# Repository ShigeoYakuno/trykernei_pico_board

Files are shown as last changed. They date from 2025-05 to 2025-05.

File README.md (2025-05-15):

# ベースボード

## 方針
- カバーなどが安く買え、種類も豊富なためラズパイ4Bサイズで作る。
- 40pinのコネクタ、M2.5サイズのホールもそのまま採用
- プログラム変更をSDカード経由で行いたいため、カードスロットを標準搭載する
- 3.7Vリポバッテリーでも起動できるよう構成する

### 全体



### 表面


### 裏面



## 3D正面


## 3D裏面



## BOM


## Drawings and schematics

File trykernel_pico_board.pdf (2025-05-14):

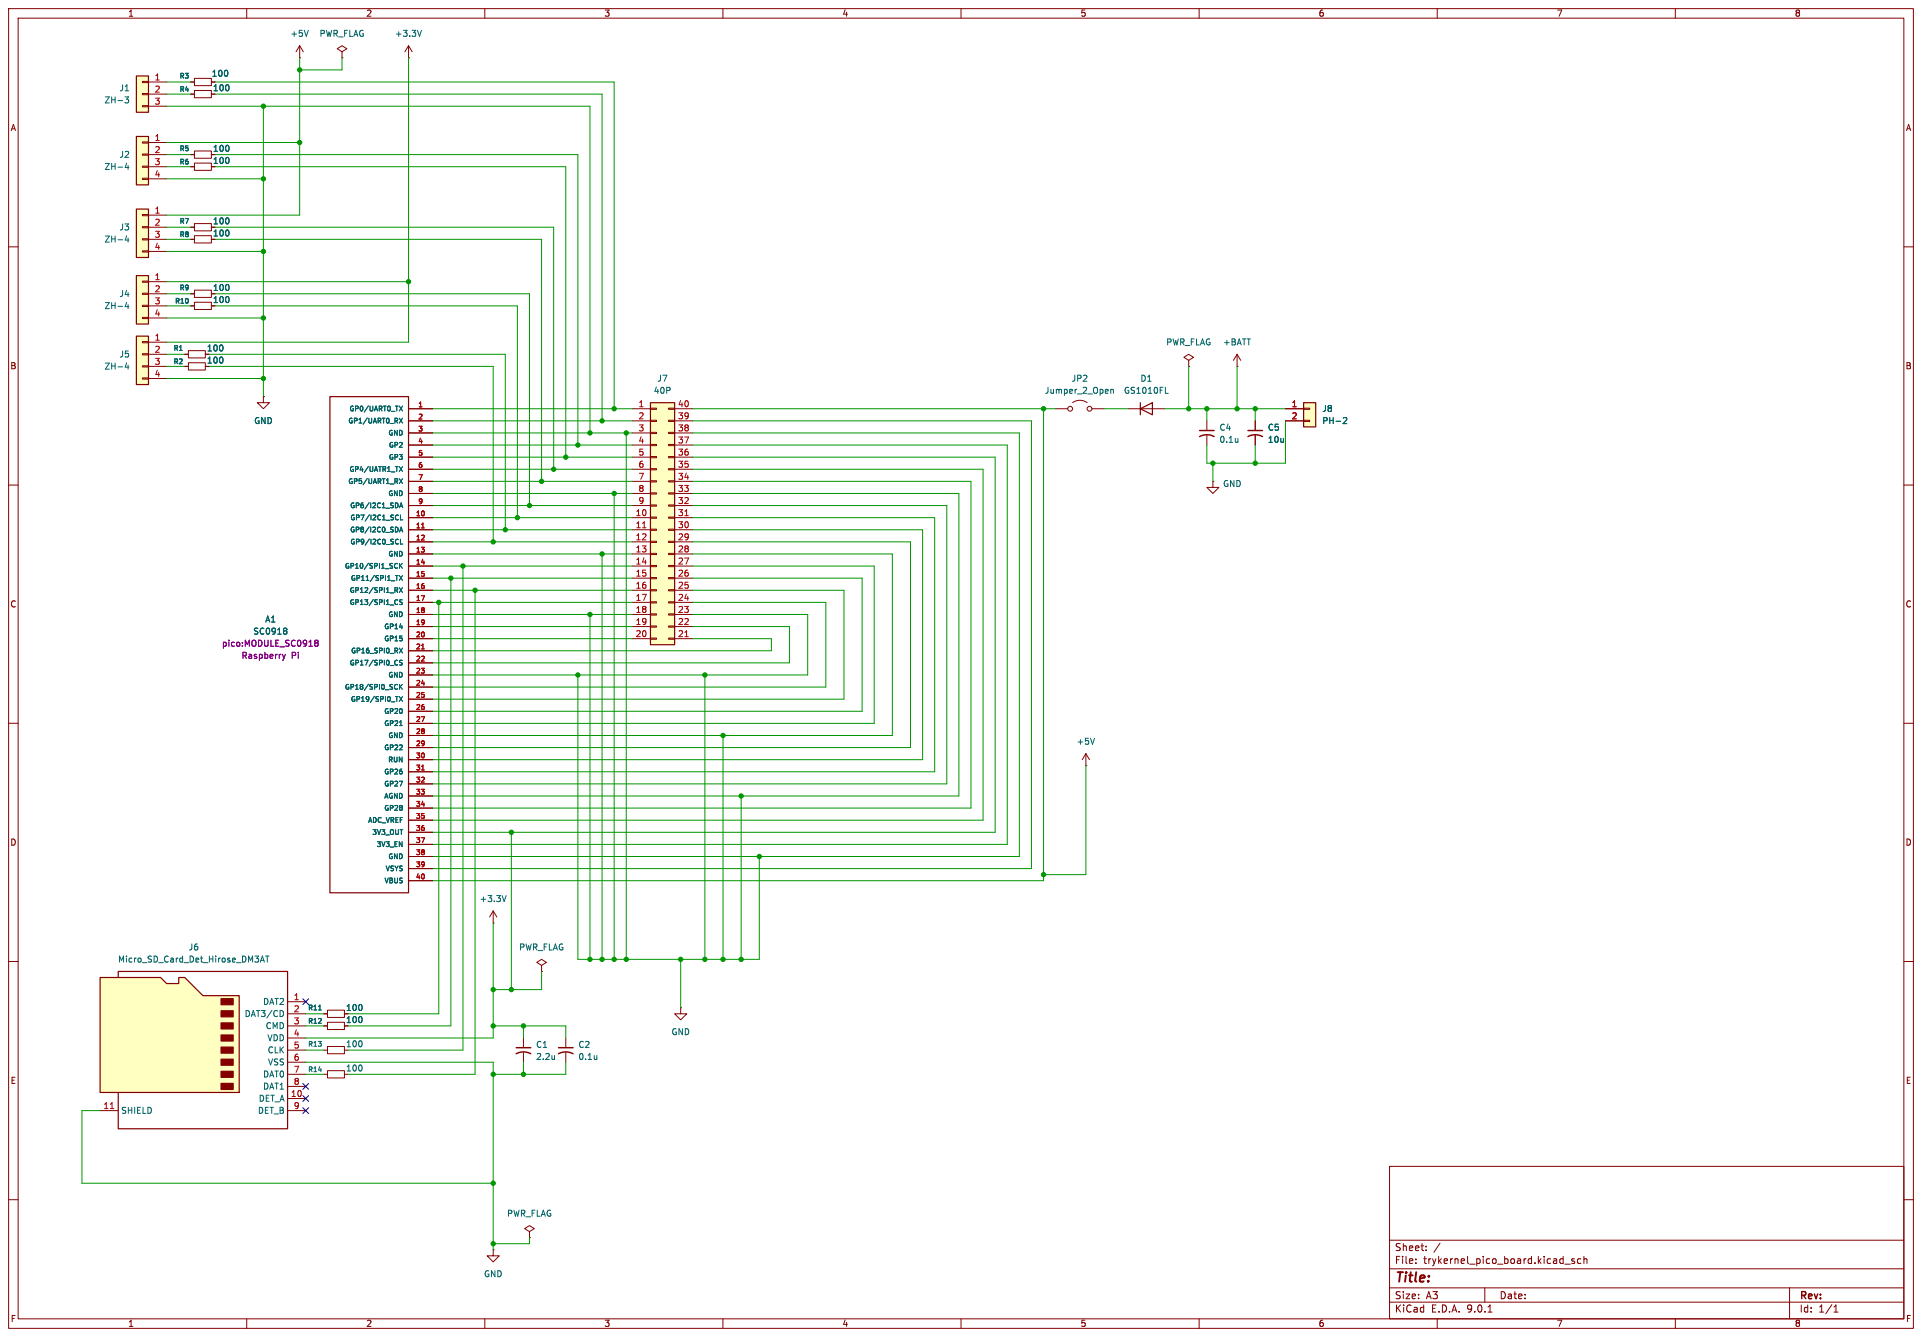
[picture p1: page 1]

Id: 1/1 Title: File: trykernel_pico_board.kicad_sch Sheet: /

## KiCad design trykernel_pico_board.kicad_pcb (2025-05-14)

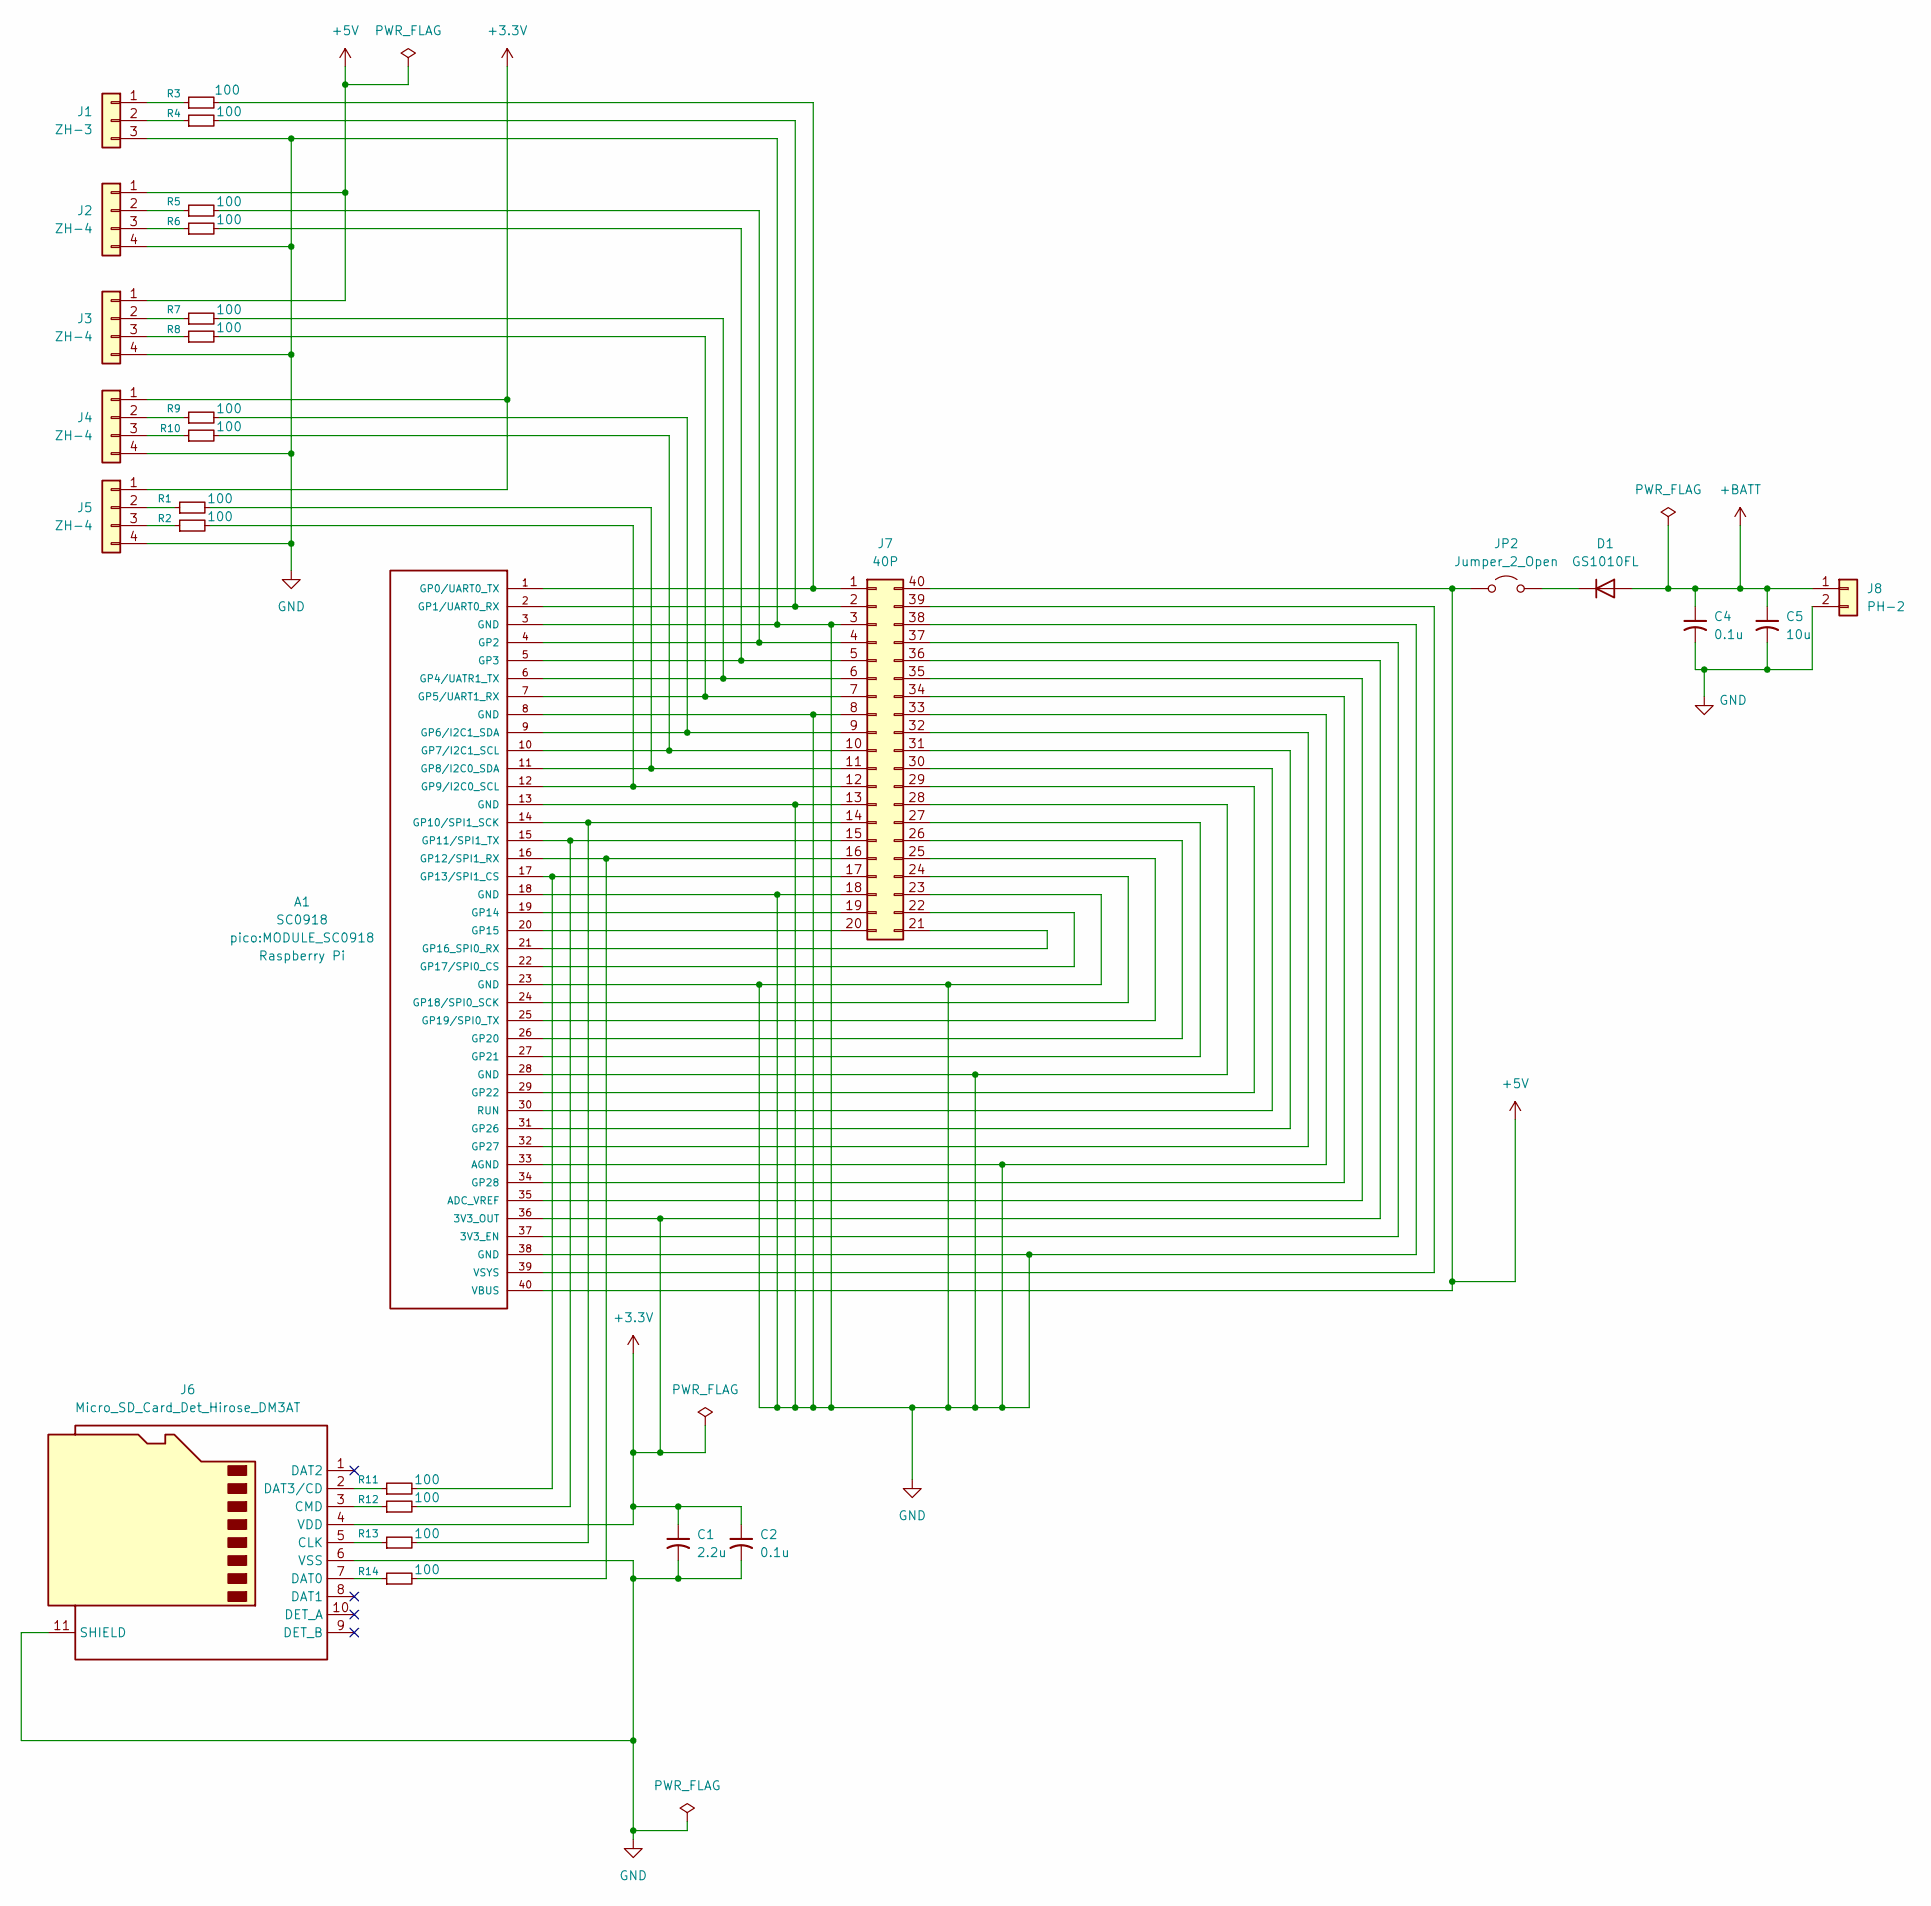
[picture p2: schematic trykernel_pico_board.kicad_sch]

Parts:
A1: SC0918; MODULE_SC0918; PARTREV 1.6
C1: 2.2u; C_0603_1608Metric_Pad1.08x0.95mm_HandSolder
C2: 0.1u; C_0603_1608Metric_Pad1.08x0.95mm_HandSolder
C4: 0.1u; C_0805_2012Metric_Pad1.18x1.45mm_HandSolder
C5: 10u; C_0805_2012Metric_Pad1.18x1.45mm_HandSolder
D1: GS1010FL; D_SOD-123
J1: ZH-3; JST_ZH_B3B-ZR_1x03_P1.50mm_Vertical
J2, J3, J4, J5: ZH-4; JST_ZH_B4B-ZR_1x04_P1.50mm_Vertical
J6: Micro_SD_Card_Det_Hirose_DM3AT; microSD_HC_Hirose_DM3AT-SF-PEJM5
J7: 40P; RPI_Hat_B+
J8: PH-2; JST_PH_B2B-PH-K_1x02_P2.00mm_Vertical
JP2: Jumper_2_Open; Pin_Header_Straight_1x02
R1, R2, R3, R4, R5, R6, R7, R8, R9, R10, R11, R12, R13, R14: 100; R_0603_1608Metric_Pad0.98x0.95mm_HandSolder

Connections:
+3.3V: A1.36 (3V3_OUT), C1.1, C2.1, J4.1, J5.1, J6.4 (VDD), J7.36
+5V: A1.40 (VBUS), J2.1, J3.1, J7.40, JP2.1 (A)
+BATT: C4.1, C5.1, D1.2 (A), J8.1
GND: A1.3 (GND), A1.8 (GND), A1.13 (GND), A1.18 (GND), A1.23 (GND), A1.28 (GND), A1.33 (AGND), A1.38 (GND), C1.2, C2.2, C4.2, C5.2, J1.3, J2.4, J3.4, J4.4, J5.4, J6.6 (VSS), J6.11 (SHIELD), J7.3, J7.8, J7.13, J7.18, J7.23, J7.28, J7.33, J7.38, J8.2
unnamed: A1.37 (3V3_EN), J7.37
unnamed: A1.35 (ADC_VREF), J7.35
unnamed: A1.1 (GP0/UART0_TX), J7.1, R3.2
unnamed: A1.2 (GP1/UART0_RX), J7.2, R4.2
unnamed: A1.4 (GP2), J7.4, R5.2
unnamed: A1.5 (GP3), J7.5, R6.2
unnamed: A1.6 (GP4/UATR1_TX), J7.6, R7.2
unnamed: A1.7 (GP5/UART1_RX), J7.7, R8.2
unnamed: A1.9 (GP6/I2C1_SDA), J7.9, R9.2
unnamed: A1.10 (GP7/I2C1_SCL), J7.10, R10.2
unnamed: A1.11 (GP8/I2C0_SDA), J7.11, R1.2
unnamed: A1.12 (GP9/I2C0_SCL), J7.12, R2.2
unnamed: A1.14 (GP10/SPI1_SCK), J7.14, R13.2
unnamed: A1.15 (GP11/SPI1_TX), J7.15, R12.2
unnamed: A1.16 (GP12/SPI1_RX), J7.16, R14.2
unnamed: A1.17 (GP13/SPI1_CS), J7.17, R11.2
unnamed: A1.19 (GP14), J7.19
unnamed: A1.20 (GP15), J7.20
unnamed: A1.21 (GP16_SPI0_RX), J7.21
unnamed: A1.22 (GP17/SPI0_CS), J7.22
unnamed: A1.24 (GP18/SPI0_SCK), J7.24
unnamed: A1.25 (GP19/SPI0_TX), J7.25
unnamed: A1.26 (GP20), J7.26
unnamed: A1.27 (GP21), J7.27
unnamed: A1.29 (GP22), J7.29
unnamed: A1.31 (GP26), J7.31
unnamed: A1.32 (GP27), J7.32
unnamed: A1.34 (GP28), J7.34
unnamed: A1.30 (RUN), J7.30
unnamed: A1.39 (VSYS), J7.39
unnamed: D1.1 (K), JP2.2 (B)
unnamed: J1.1, R3.1
unnamed: J1.2, R4.1
unnamed: J2.2, R5.1
unnamed: J2.3, R6.1
unnamed: J3.2, R7.1
unnamed: J3.3, R8.1
unnamed: J4.2, R9.1
unnamed: J4.3, R10.1
unnamed: J5.2, R1.1
unnamed: J5.3, R2.1
unnamed: J6.5 (CLK), R13.1
unnamed: J6.3 (CMD), R12.1
unnamed: J6.7 (DAT0), R14.1
unnamed: J6.2 (DAT3/CD), R11.1

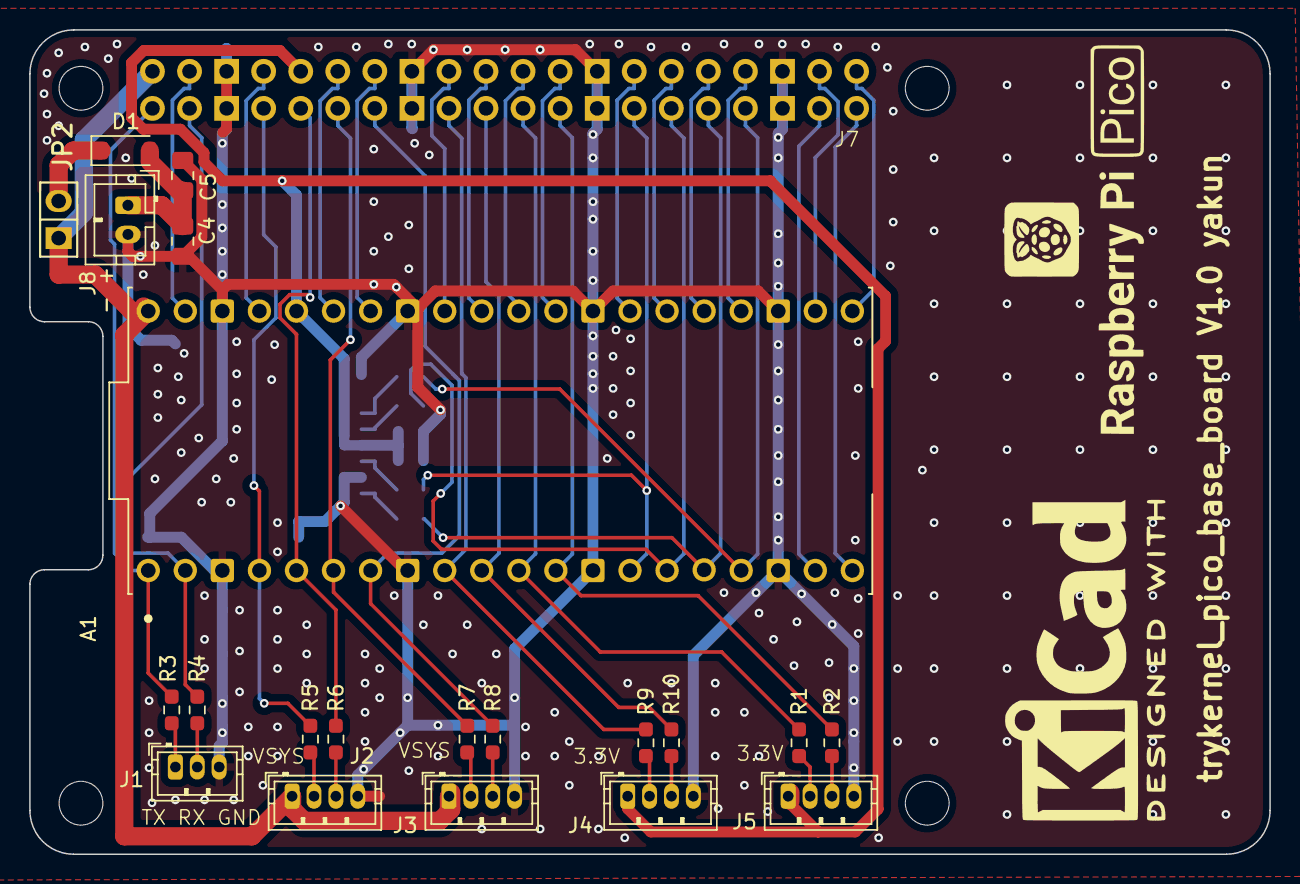
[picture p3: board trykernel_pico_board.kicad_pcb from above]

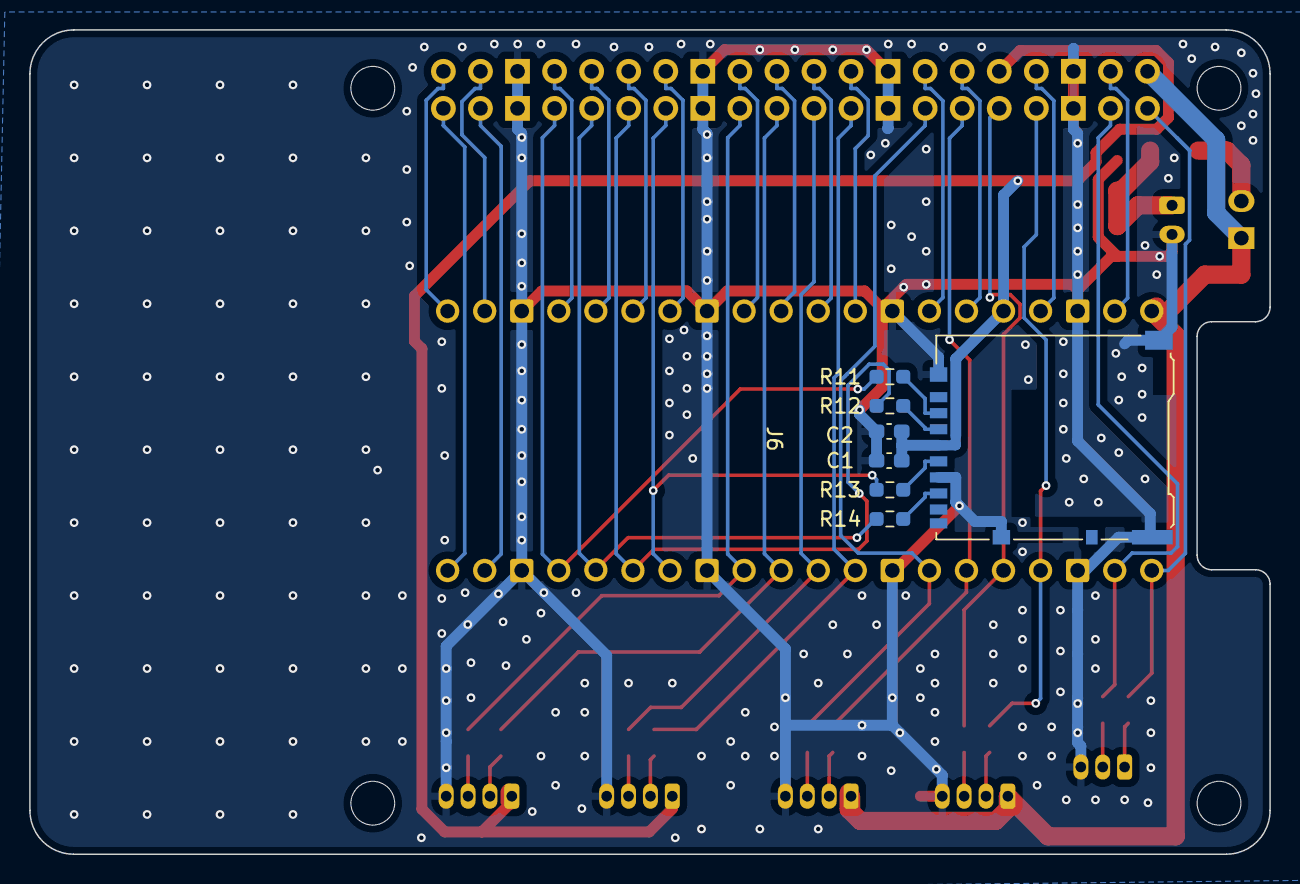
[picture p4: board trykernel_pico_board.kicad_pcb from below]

Board: 2 copper layers, 85.0 x 56.5 mm, 29 parts (7 on the bottom side), 49 nets.

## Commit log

2025-05-01 空プロジェクトをあげただけ
    [trykernel_pico_board.kicad_pcb, trykernel_pico_board.kicad_sch]
2025-05-01 ベース基板とpicoを追加
    [trykernel_pico_board.kicad_sch]
2025-05-14 version1.0 発注したもの
    [trykernel_pico_board.dsn, trykernel_pico_board.kicad_pcb, trykernel_pico_board.kicad_sch]
